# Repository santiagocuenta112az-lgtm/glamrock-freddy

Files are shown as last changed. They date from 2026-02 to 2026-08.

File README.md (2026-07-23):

# glamrock-freddy
hello superstar!!!!!

ax7fsq

¿who am i?

I'm Glamrock Freddy, an animatronic robot designed to inspire people and make learning complex topics fun, interactive, and accessible. Through me, students can discover how subjects like mechanics, physics, electronics, computer science, and even biology come together to create something that can move, see, speak, and interact with the world.

I was designed to be open, modular, easy to build, and easy to program, so that anyone with curiosity—not necessarily expensive equipment—can learn from me, improve me, and even build their own version.

But... why would someone spend months building an animatronic like me?

Growing up, I often felt that education focused too heavily on memorizing facts instead of understanding how knowledge can be applied to solve real problems. We constantly talk about building a better future, yet that future cannot exist if science and engineering remain confined to textbooks instead of becoming tools for creation and innovation.

That frustration became the beginning of this project.

I was created to show that the subjects many students consider difficult, abstract, or even boring are actually the foundation of incredible things. Every gear demonstrates mechanics. Every servo teaches control systems. Every electronic circuit applies physics. Every line of code becomes intelligence and behavior. Every camera, sensor, and algorithm transforms mathematics into something that can perceive and interact with the world.

My goal is to help reduce educational inequality by bringing robotics directly to students. I hope to visit as many schools as possible, showing that engineering is not just something found in universities or large companies—it is something anyone can learn with curiosity, creativity, and perseverance.

I wasn't built just to entertain people.

I was built to make them curious.

¿Where have I been?

Curiosity shouldn't be limited to a single classroom. That's why my mission is to travel to as many schools and universities as possible—not only across my country, but, why not, around the world. Every stop on this map represents new conversations, new ideas, and new friendships. I don't expect everyone I meet to become an engineer. If one student leaves inspired to become a scientist, an artist, a writer, a teacher, or simply someone who never stops asking questions, then I've accomplished my mission. This is my journey so far.

(My first visit to a school)
Perú-Lima (Villa El Salvador)




¿How does my mind work?

Whenever someone wants to talk to me, the first thing they do is open the hatch on my chest. Inside, they'll find a microphone and a "Listen" button. Once the button is pressed, I begin paying attention.

From that moment, I carefully listen to every word. My onboard computer processes what I hear, understands the question using artificial intelligence, and prepares a response. A few moments later, I speak back, moving my mouth in sync with my voice to make the conversation feel as natural as possible.

ax7ipx

But that's only what happens on the outside...

Let's take a look inside my mind.

AI System workflow

1.- The user picks up the microphone and presses the "Listen" button on my screen.
2.- The Raspberry Pi records the user's voice and uses Whisper to transcribe the spoken words into text.
3.- The transcribed text is sent to an api of groq (an AI).
4.- The AI processes the request, generates a response, and sends it back to the Raspberry Pi.
5.- The Raspberry Pi converts the generated text into speech using a Text-to-Speech (TTS) system while simultaneously synchronizing my mouth movements to match the audio.

¿How can I see you?

i use two cameras into my eyes to see 







this cameras are conected to a raspberry pi 5, use yolo to detect objects, persons, and record.





How do I move?
i use servomotors and planetary gearboxes to move mi arms and head











 this is the planetaryt gearbox
 
 

The project uses Bottango to function. (https://www.bottango.com)

What's inside me?
i use arduinos to control the servos and a raspberry pi 5 for the ai system







 to control mi servos I use bottango that is an program to make animations whit servos steppers and other motors, it´s open source, here is the link (https://www.bottango.com)

ax7j1h (1)

How was I built?

Building me was a long and challenging journey. I wasn't created from a detailed blueprint or years of experience. Instead, I was built through curiosity, experimentation, and countless hours of learning.

Every obstacle became an opportunity to discover something new. Every failed prototype led to a better design. Every mistake became another lesson. Little by little, each improvement helped shape the robot I am today.

the robot in the start of the project
MVI_4156

a power converter that i destroyed



 a piece that i don´t designed in a good way

 the prototipes of the eyes
 

 




 the final eyes
 




Now that my development is nearing completion, I have a new goal.

I want to make my construction process as simple and accessible as possible. Every mechanism, every circuit, and every line of code is being documented so that anyone—regardless of their previous experience—can understand how I work, learn from me, and even build their own version.

After all, knowledge becomes far more valuable when it is shared.

What's next?

i have emore ideas for the robot, there´s most of them

1.- Improve the chest mecanism
2.- do the ai for the robot talk whit the user in more natural way
3.- organize the connections to make them looks more hide
4.- do the 4 missing essays to explain hte concepts
5.- animate the robot whit the content of the essays
6.- do a narrative documentary like cosmos (of carl sagan) to explain more the concepts
7.- go for more schools

more detailed explanation of my build on hack club

https://macondo.hackclub.com/projects/11732

Here´s the bom and the wiring diagram



Captura de pantalla 2026-04-10 235814

bill of materials

[stasis_budget_hyperlinks.ods](https://github.com/user-attachments/files/30323746/stasis_budget_hyperlinks.ods)

(adaptation and translation of the texts form spanish to english are made by chatgpt, because my writing on english is not perfect and i need to made the readme understandable to all the people that see the project)

The project uses some existing files from the internet; here is a direct quote.

Autor: gabgra11
Licencia: CC BY-NC-SA
This model was used to make the animatronic's head; it was modified to fulfill that function
Fuente:
https://www.printables.com/model/553299-glamrock-freddy-wearable-mask-with-hinged-jaw

Autor: Hannah
Licencia: BY-NC-SA
This is the base model of the animatronic's casing; it has been scaled, modified, and adapted to the different mechanisms necessary for the project.
Fuente:
https://www.myminifactory.com/es/object/3d-print-glamrock-freddy-figure-340562

Autor: emccarron
Licencia:CC BY-NC-SA
The model will be used to create the robot's hands; currently, the model is scaled, but it needs to be adapted to fit the project.
Fuente:
https://www.thingiverse.com/thing:7145273

Autor: Paul6700
Licencia: Creative Commons (4.0 International License)
The model was adapted to fit the animatronic; the eyes have a space for an OV5647 model camera.
Fuente:
https://www.printables.com/model/1435865-46mm-animatronic-single-eye-four-servo-design

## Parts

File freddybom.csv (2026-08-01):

name | description | total cost | quantity | link | distributor
PETG-CR | Filamento para carcasa | 85.53 | 6 | enlace de compra | digitalz3d
ABS Landu | Filamento para carcasa | 64.15 | 5 | enlace de compra | digitalz3d
Rapid PETG Elegoo | Filamento para carcasa | 28.51 | 2 | enlace de compra | digitalz3d
PLA K3D | Filamento para carcasa | 28.51 | 2 | enlace de compra | krear3d
ABS Polymaker | Filamento para carcasa | 37.06 | 2 | enlace de compra | krear3d
PLA Carbon Fiber Polymaker 1kg | Filamento estructural | 28.51 | 1 | enlace de compra | krear3d
Servo MG996R | Actuador | 4.75 | 6 | enlace de compra | aliexpres
Servo MG90S | Actuador | 2.28 | 10 | enlace de compra | aliexpres
Servo DS2340 | Actuador | 11.41 | 4 | enlace de compra | aliexpres
Servo RDS51160 | Actuador alta potencia | 28.51 | 2 | enlace de compra | aliexpres
Servo DS3235MG doble eje | Actuador doble eje | 16.39 | 4 | enlace de compra | aliexpres
Arduino Mega | Controlador principal | 15.97 | 2 | enlace de compra | aliexpres
Arduino Uno | Controlador | 4.28 | 1 | enlace de compra | aliexpres
Arduino Nano | Controlador compacto | 4.28 | 1 | enlace de compra | aliexpres
PCA9685 | Driver PWM servos | 3.42 | 5 | enlace de compra | aliexpres
Buck Converter 46V-5V 6A | Regulación de voltaje | 19.96 | 1 | enlace de compra | aliexpres
Fuente 12V 5A | Alimentación | 22.81 | 1 | enlace de compra | aliexpres
Fuente 24V 16.7A | Alimentación principal | 37.06 | 1 | enlace de compra | aliexpres
Fuente 12V 10A | Alimentación secundaria | 18.53 | 1 | enlace de compra | aliexpres
Extensión servo 15cm | Cableado | 7.13 | 1 | enlace de compra | temu
Cables Dupont | Cableado | 1.43 | 1 | enlace de compra | aliexpres
Extensión servo 1m | Cableado | 11.4 | 1 | enlace de compra | aliexpres

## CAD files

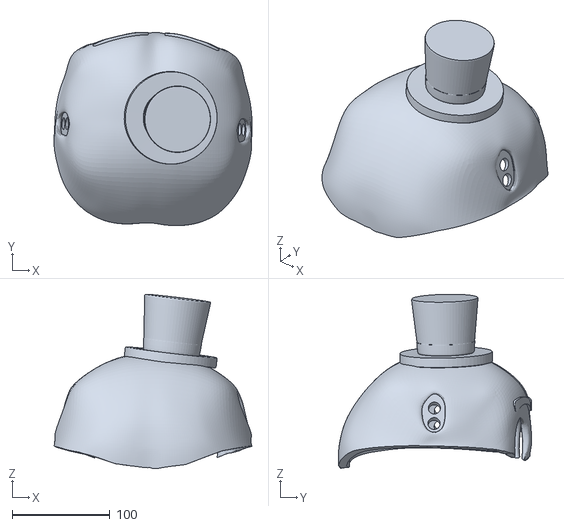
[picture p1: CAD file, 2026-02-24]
cara/caraalta.stl
202.5 x 197.8 x 178.4

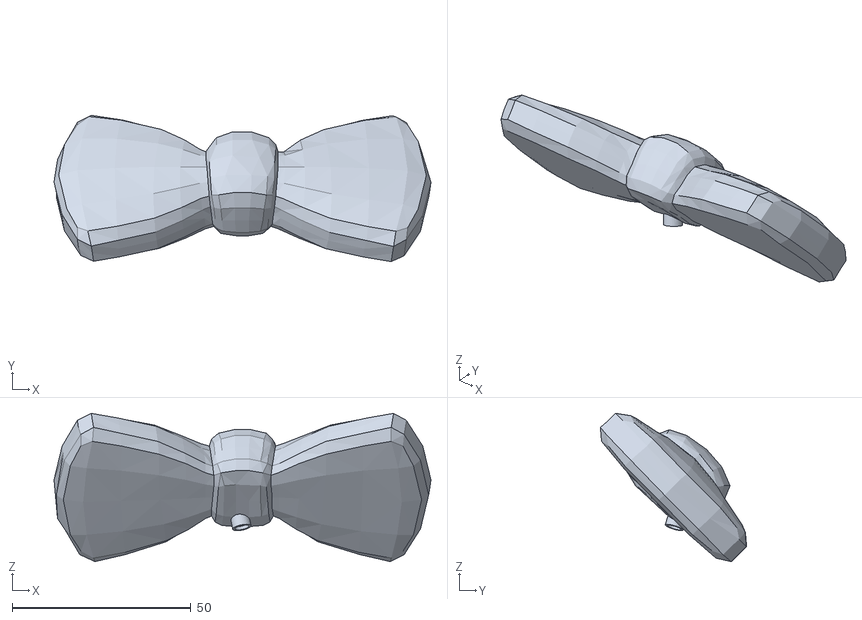
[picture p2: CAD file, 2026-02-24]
cuerpo/corbata1111.stl
105.4 x 40.9 x 41.4

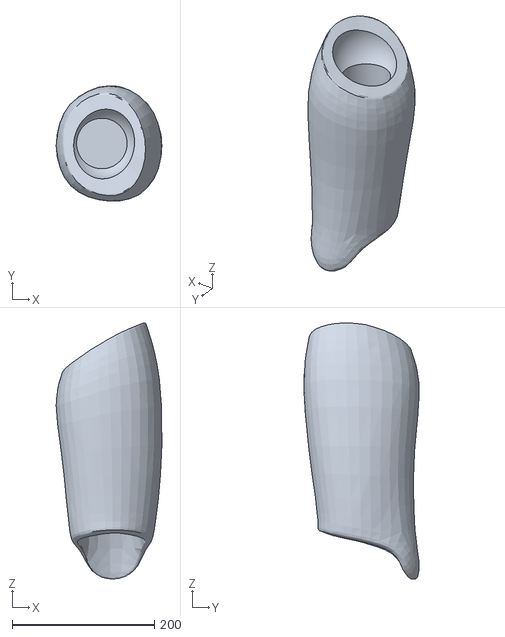
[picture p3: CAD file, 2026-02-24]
cuerpo/extremidades/muslo.stl
148.5 x 161.9 x 359.4

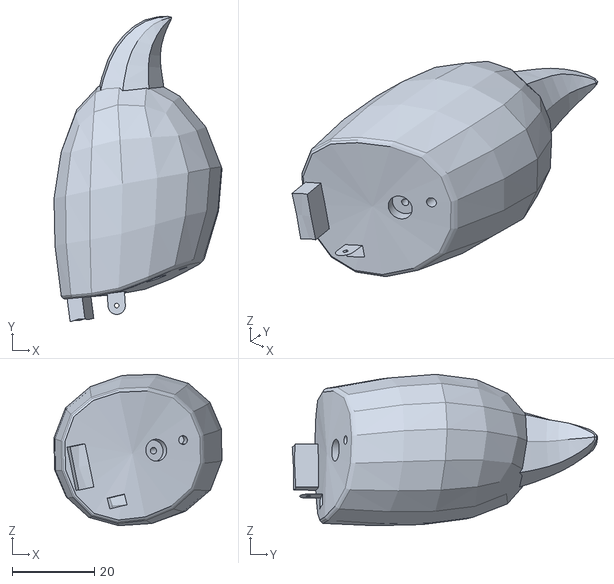
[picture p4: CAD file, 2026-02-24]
mano/dedo.stl
40.8 x 74.2 x 36.8

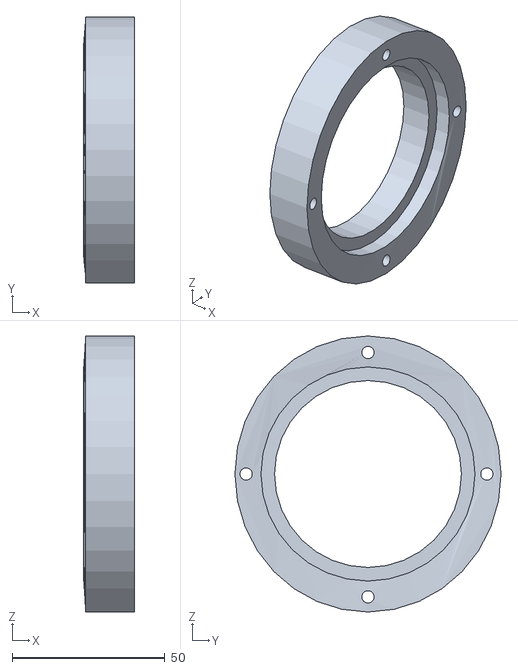
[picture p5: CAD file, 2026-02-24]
mis mecanismos/brazo/encaje.stl
16.5 x 87.0 x 90.2

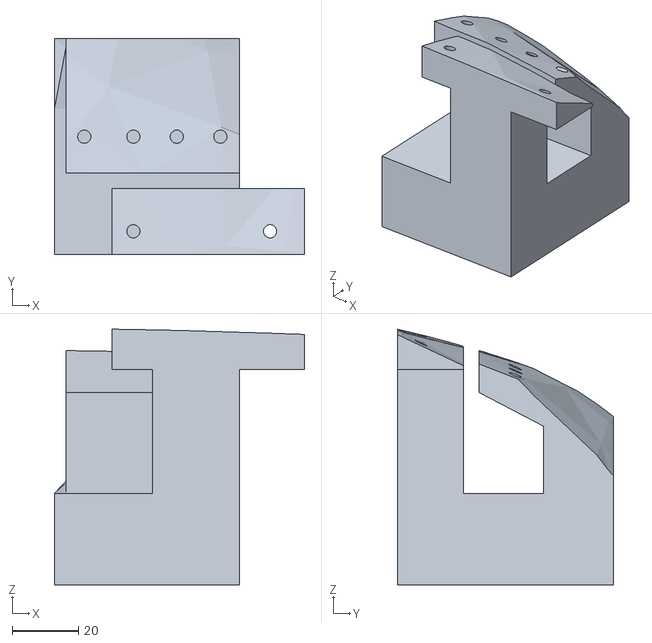
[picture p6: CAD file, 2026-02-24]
mis mecanismos/mecanismo de placa alta/1.stl
75.5 x 65.3 x 77.2

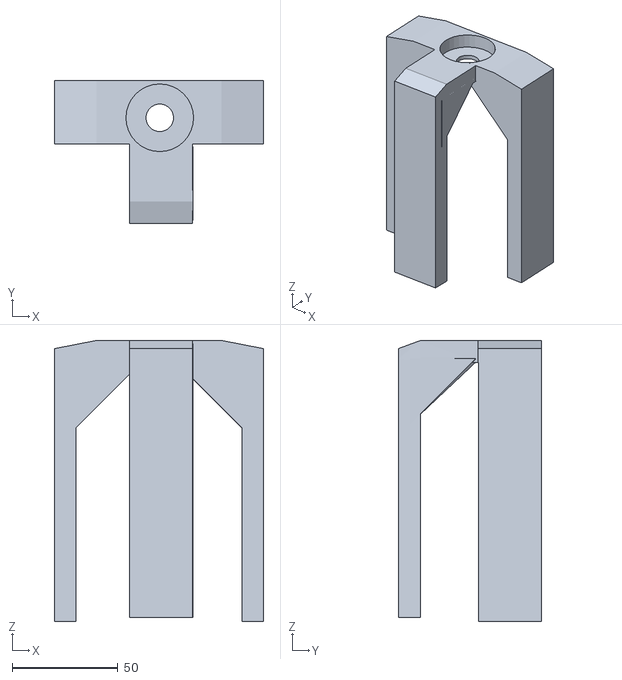
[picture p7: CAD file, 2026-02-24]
mis mecanismos/mecanismo giro pecho/3.stl
98.9 x 67.8 x 133.0

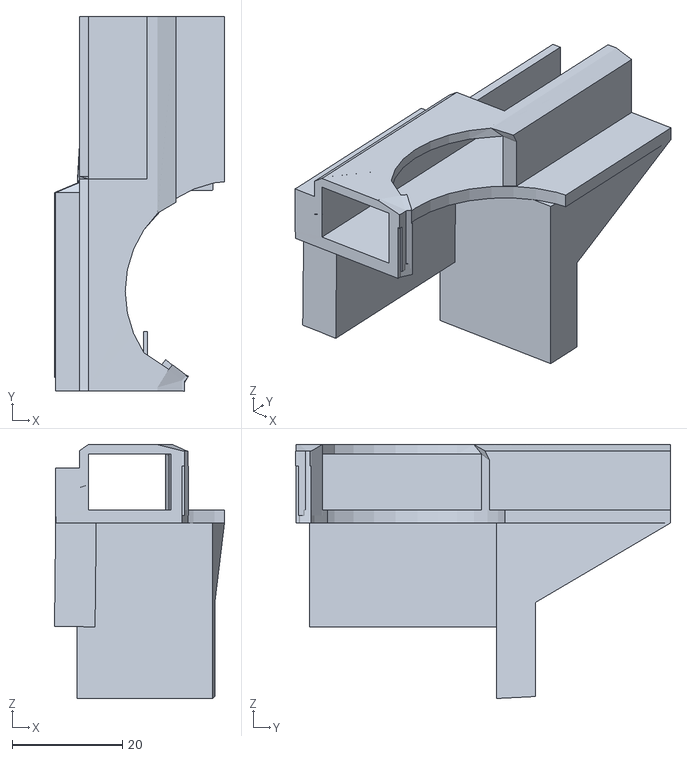
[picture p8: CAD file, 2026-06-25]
mis mecanismos/mecanismo placa baja/soporte.stl
30.9 x 68.2 x 46.2

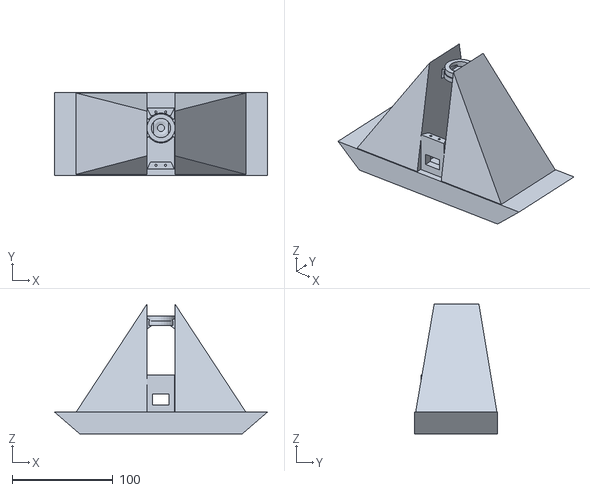
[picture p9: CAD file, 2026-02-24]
mis mecanismos/pecho/soporte central.stl
211.4 x 82.1 x 128.7

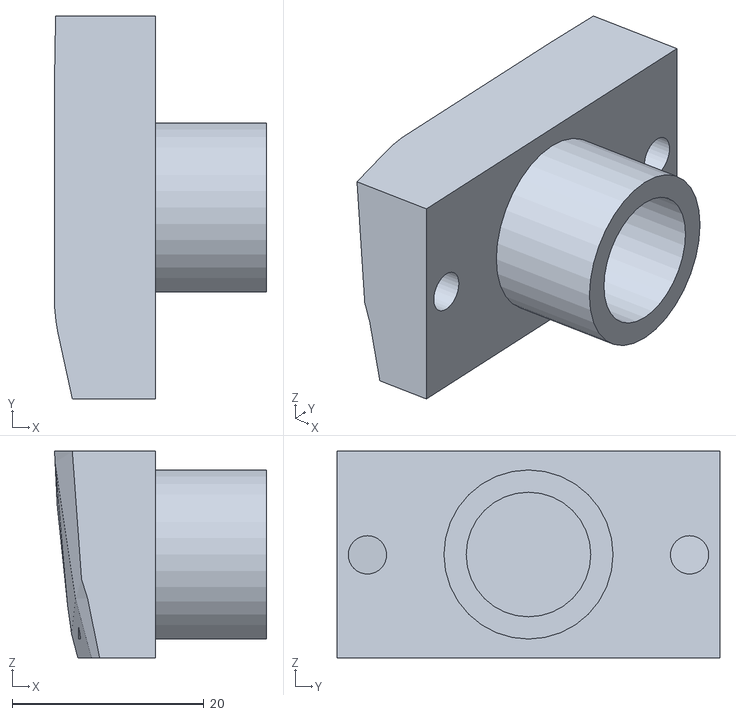
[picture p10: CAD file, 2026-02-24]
mis mecanismos/soportes/3p.stl
22.1 x 40.0 x 21.6

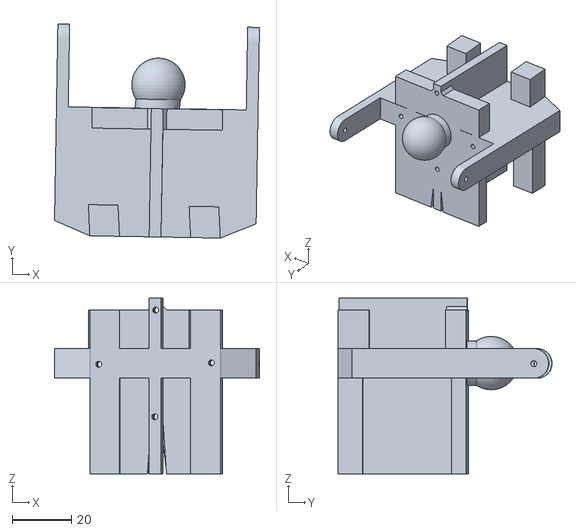
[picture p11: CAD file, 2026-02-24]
ojos/mecanismo.stl
69.1 x 72.2 x 59.2

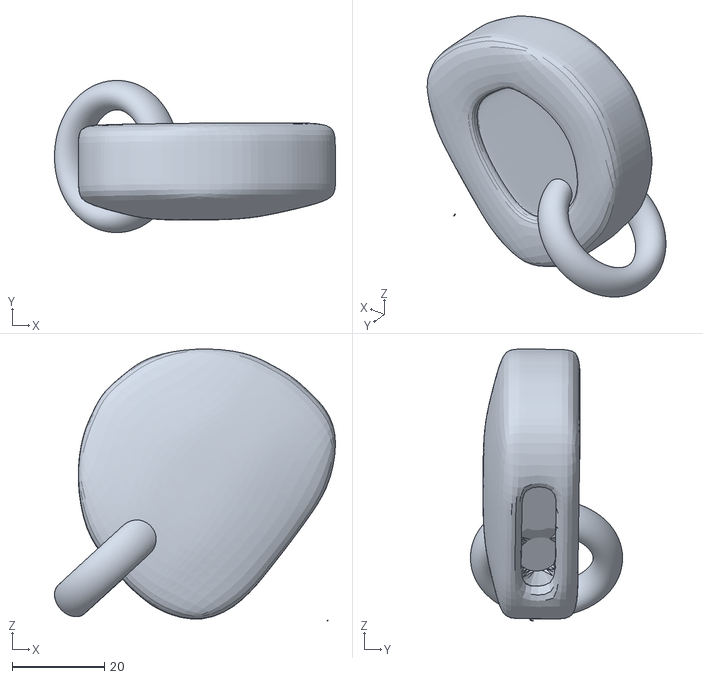
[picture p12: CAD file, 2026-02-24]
cara/oreja 1.stl
61.1 x 33.1 x 59.1

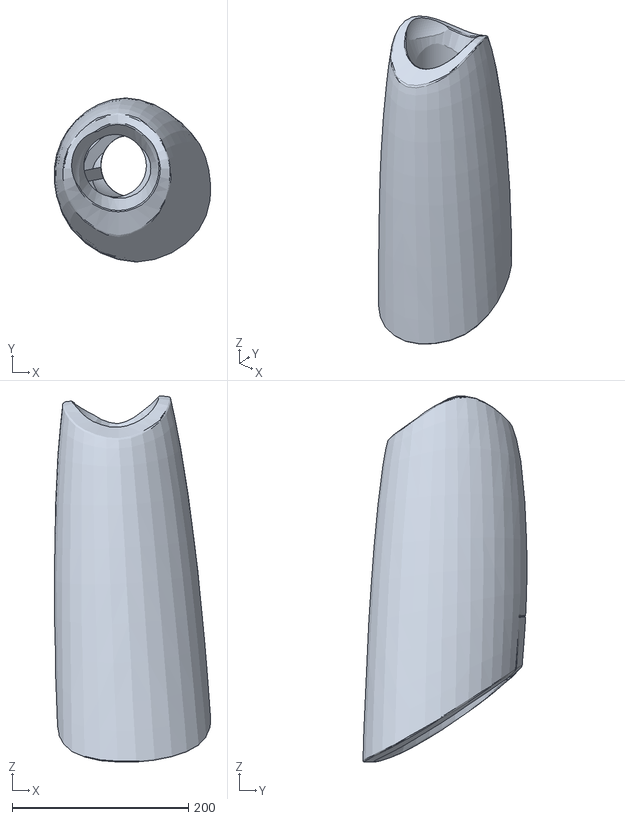
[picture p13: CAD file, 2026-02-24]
cuerpo/extremidades/pierna.stl
177.4 x 186.4 x 415.9

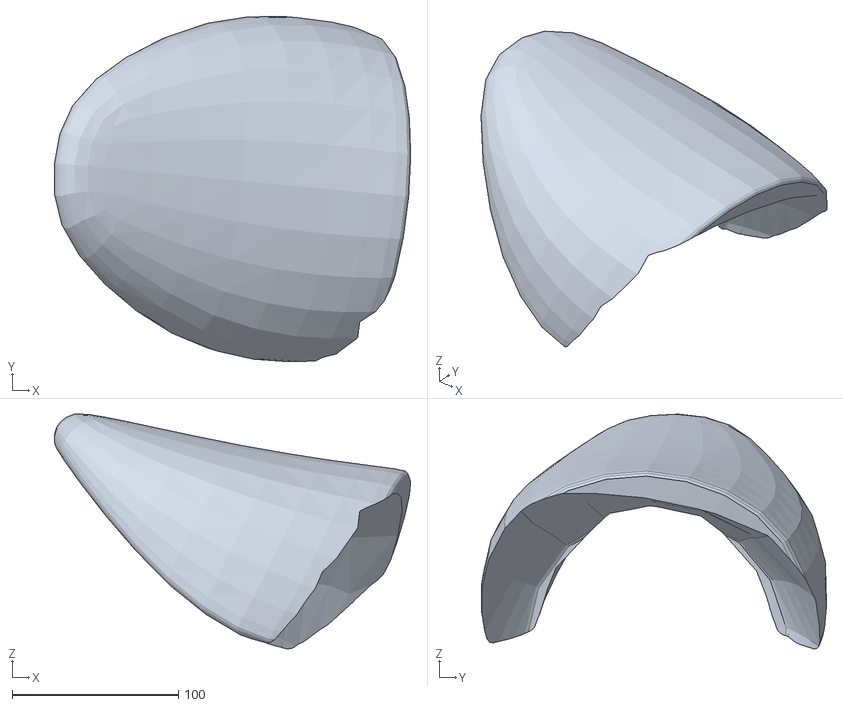
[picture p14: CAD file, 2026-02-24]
cuerpo/hombrera.stl
214.4 x 207.5 x 141.2

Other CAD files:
robot.step
mano/mano.stl
mis mecanismos/brazo/planetas.stl
mis mecanismos/mecanismo de placa alta/3.stl
cara/mandibula.stl
cara/midface.stl
cara/oreja 2.stl
cuerpo/abdomen.stl
cuerpo/extremidades/antebtrazo.stl
cuerpo/extremidades/brazo.stl
cuerpo/extremidades/pie.stl
cuerpo/palcaup.stl
cuerpo/pecho.stl
cuerpo/pelvis.stl
cuerpo/placadown.stl
mano/dedomid.stl
mis mecanismos/brazo/conexionsoporteservo.stl
mis mecanismos/brazo/corona.stl
mis mecanismos/brazo/portaplanetas.stl
mis mecanismos/brazo/salidadetorque.stl
mis mecanismos/brazo/sol.stl
mis mecanismos/brazo/soporte brazo.stl
mis mecanismos/brazo/soporte servo.stl
mis mecanismos/mecanismo de placa alta/2.stl
mis mecanismos/mecanismo de placa alta/engranaje.stl
mis mecanismos/mecanismo giro pecho/1.stl
mis mecanismos/mecanismo giro pecho/2.stl
mis mecanismos/mecanismo placa baja/1.stl
mis mecanismos/mecanismo placa baja/2.stl
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

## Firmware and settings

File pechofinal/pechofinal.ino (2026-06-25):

#include <Servo.h>

//--------------------------------------------------
// SENSOR HC-SR04
//--------------------------------------------------
#define TRIG_PIN 2
#define ECHO_PIN 3

#define DISTANCIA_ACTIVACION 35

//--------------------------------------------------
// SERVOS
//--------------------------------------------------
Servo mg1;   // D7
Servo mg2;   // D5

Servo ds1;   // D10
Servo ds2;   // D11

//--------------------------------------------------
// CALIBRACIÓN
// (Modificar estos valores según tu mecanismo)
//--------------------------------------------------

// MG996R
int MG1_CERRADO = 50;
int MG1_ABIERTO = 160;

int MG2_CERRADO = 180; //listo//
int MG2_ABIERTO = 60;

// DS3235 (invertidos)
int DS1_CERRADO = 160;
int DS1_ABIERTO = 130;

int DS2_CERRADO = 150; //listo//
int DS2_ABIERTO = 100;

//--------------------------------------------------
#define RETRASO_ENTRE_GRUPOS 600
#define VELOCIDAD 15
//--------------------------------------------------

bool abierto = false;
bool esperandoLiberacion = false;

//--------------------------------------------------
// MEDIR DISTANCIA
//--------------------------------------------------
long medirDistancia() {

  digitalWrite(TRIG_PIN, LOW);
  delayMicroseconds(2);

  digitalWrite(TRIG_PIN, HIGH);
  delayMicroseconds(10);

  digitalWrite(TRIG_PIN, LOW);

  long duracion = pulseIn(ECHO_PIN, HIGH, 25000);

  if (duracion == 0)
    return 999;

  return duracion * 0.034 / 2;
}

//--------------------------------------------------
// MOVER DOS SERVOS AL MISMO TIEMPO
//--------------------------------------------------
void moverPar(
  Servo &s1,
  Servo &s2,
  int inicio1,
  int fin1,
  int inicio2,
  int fin2) {

  int pasos = max(abs(fin1 - inicio1), abs(fin2 - inicio2));

  if (pasos == 0)
    return;

  float pos1 = inicio1;
  float pos2 = inicio2;

  float inc1 = (float)(fin1 - inicio1) / pasos;
  float inc2 = (float)(fin2 - inicio2) / pasos;

  for (int i = 0; i <= pasos; i++) {

    s1.write((int)pos1);
    s2.write((int)pos2);

    pos1 += inc1;
    pos2 += inc2;

    delay(VELOCIDAD);
  }

  s1.write(fin1);
  s2.write(fin2);
}

//--------------------------------------------------
// ABRIR PECHO
//--------------------------------------------------
void abrirPecho() {

  // MG996R primero
  moverPar(
    mg1, mg2,
    MG1_CERRADO, MG1_ABIERTO,
    MG2_CERRADO, MG2_ABIERTO
  );

  delay(RETRASO_ENTRE_GRUPOS);

  // DS3235 después
  moverPar(
    ds1, ds2,
    DS1_CERRADO, DS1_ABIERTO,
    DS2_CERRADO, DS2_ABIERTO
  );
}

//--------------------------------------------------
// CERRAR PECHO
//--------------------------------------------------
void cerrarPecho() {

  // DS3235 primero
  moverPar(
    ds1, ds2,
    DS1_ABIERTO, DS1_CERRADO,
    DS2_ABIERTO, DS2_CERRADO
  );

  delay(RETRASO_ENTRE_GRUPOS);

  // MG996R después
  moverPar(
    mg1, mg2,
    MG1_ABIERTO, MG1_CERRADO,
    MG2_ABIERTO, MG2_CERRADO
  );
}

//--------------------------------------------------
// SETUP
//--------------------------------------------------
void setup() {

  pinMode(TRIG_PIN, OUTPUT);
  pinMode(ECHO_PIN, INPUT);

  mg1.attach(7);
  mg2.attach(5);

  ds1.attach(10);
  ds2.attach(11);

  mg1.write(MG1_CERRADO);
  mg2.write(MG2_CERRADO);

  ds1.write(DS1_CERRADO);
  ds2.write(DS2_CERRADO);

  delay(1000);
}

//--------------------------------------------------
// LOOP
//--------------------------------------------------
void loop() {

  long distancia = medirDistancia();

  if (distancia > 0 &&
      distancia <= DISTANCIA_ACTIVACION &&
      !esperandoLiberacion) {

    esperandoLiberacion = true;

    if (!abierto) {

      abrirPecho();
      abierto = true;

    } else {

      cerrarPecho();
      abierto = false;
    }
  }

  // Esperar a que la mano se retire
  if (distancia > DISTANCIA_ACTIVACION + 10) {

    esperandoLiberacion = false;
  }

  delay(50);
}

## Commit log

2026-04-07 Add files via upload
    These are the parts of the robot I created from scratch.
    [mis piezas.f3d]
2026-07-23 Update README.md
    add the bom
